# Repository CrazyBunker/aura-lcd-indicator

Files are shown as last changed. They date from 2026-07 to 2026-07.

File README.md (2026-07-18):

# ASUS AURA — LED-контроллер и LCD-дисплей

Управление ARGB LED-контроллером ASUS AURA (0b05:19af) через USB-HID.
Включает **CLI утилиту**, **MCP сервер** для OpenCode/Claude, и **ESP32-скетч** для декодирования сигнала WS2812B.

## Фотографии

### Общий вид макета
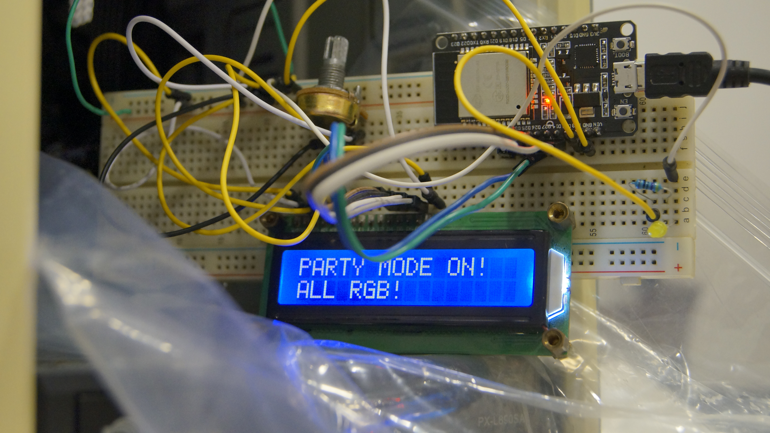
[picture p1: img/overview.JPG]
Общий вид


Плата ESP32 DevKit с подключённым HD44780 LCD (16×2) через 4-битный параллельный
интерфейс. Сигнальный провод от GPIO16 подключён к линии данных ARGB-контроллера
ASUS AURA для захвата WS2812B-кадра.

### Разъём ARGB
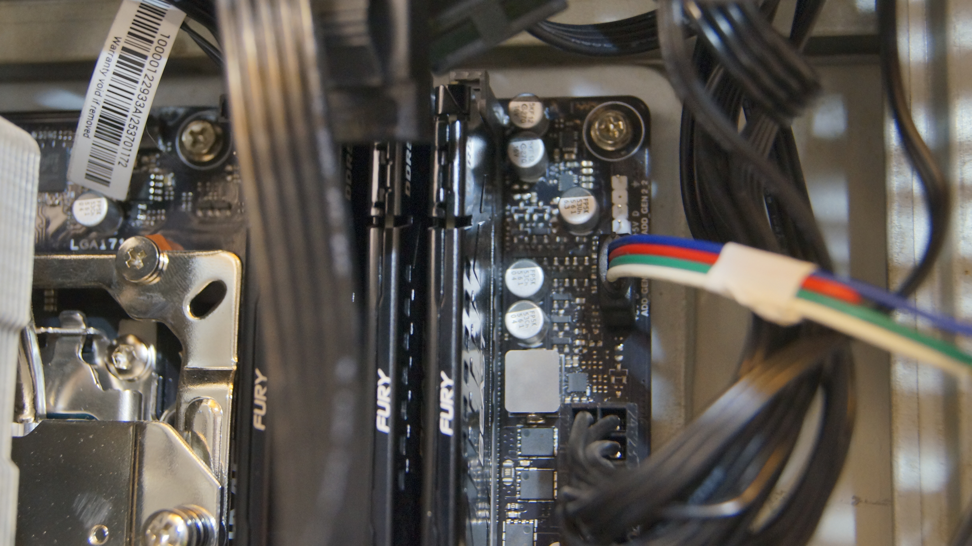
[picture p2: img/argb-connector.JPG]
Разъём ARGB


3-контактный разъём ARGB (5V, Data, GND) для подключения к материнской плате
или AURA-контроллеру. По этой линии ESP32 принимает WS2812B-сигнал через RMT.

### Схема подключения
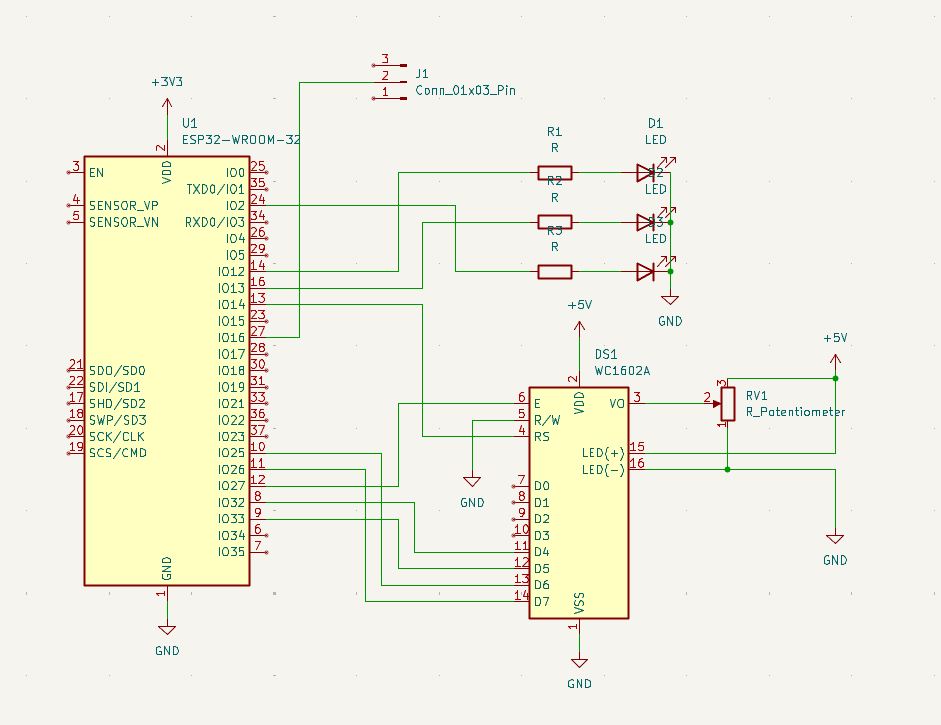
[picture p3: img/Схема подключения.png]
Схема подключения


Полная схема соединений ESP32 DevKit с HD44780 LCD, индикаторными LED и ARGB-лентой.

### Готовое устройство
Готовое устройство

ESP32 с LCD-дисплеем, подключённый к ПК. На экране отображаются данные с ARGB-контроллера.

## Быстрый старт

```bash
# Сборка (требуется Go 1.25+)
make

# Поиск устройства
./aura-indicator/bin/aura-ctl detect

# Индикатор
./aura-indicator/bin/aura-ctl set led2 static 0,0,255   # синий
./aura-indicator/bin/aura-ctl blink 255,0,0 5 200       # мигает красным
./aura-indicator/bin/aura-ctl off led2                  # выключить

# LCD дисплей (16x2, только ASCII, ≤32 символа)
./aura-indicator/bin/aura-ctl lcd "Hello, World!"

# Независимые строки (≤16 символов каждая)
./aura-indicator/bin/aura-ctl lcd-line 0 "Top line"
./aura-indicator/bin/aura-ctl lcd-line 1 "Bottom line"
```

## Примеры

Забавные скрипты для демонстрации — в каталоге `examples/`:

| Скрипт | Описание |
|---|---|
| `demo-full.sh` | Full-screen тексты: Hello World, LCD go brrrr |
| `demo-lines.sh` | Независимые строки, мигание индикатора |
| `demo-leds.sh` | 6 цветов LED + LCD не затирается |
| `demo-matrix.sh` | Отсылки к фильму «Матрица» |
| `demo-moods.sh` | Цвет индикатора под настроение |
| `demo-quotes.sh` | Знаменитые цитаты на дисплее |
| `demo-game.sh` | Игровая сцена: загрузка → бой → победа |
| `demo-rainbow.sh` | Радуга на индикаторе |
| `demo-status.sh` | Имитация прогресса (как в MCP) |

```bash
cd examples && ./demo-rainbow.sh
```

Все тексты только ASCII, ≤16 символов на строку, ≤32 full-screen.

## Сборка

```bash
make          # aura-ctl + aura-indicator → aura-indicator/bin/
make cross    # кросс-компиляция под Linux/Win/Mac (amd64 + arm64)
make clean    # удалить bin/
```

## Структура проекта

```
aura/
├── aura-indicator/         # Go-проект (CLI + MCP сервер)
│   ├── cmd/
│   │   ├── aura-ctl/       # CLI: detect, status, set, direct, lcd, blink
│   │   └── aura-indicator/ # MCP сервер (JSON-RPC stdin/stdout)
│   ├── pkg/aura/           # Go-библиотека: HID-протокол, LCD, состояние
│   ├── bin/                # Собранные бинарники
│   └── go.mod
├── aura_rmt/               # ESP32 Arduino скетч (aura_rmt.ino)
├── examples/               # Демо-скрипты
├── docs/                   # Техническая документация (PROTOCOL.md)
├── assets/                 # 3D-модели корпуса LCD (FreeCAD, STL, 3MF)
├── img/                    # Фотографии макета
├── Makefile                # Сборка проектов
└── README.md
```

## LCD (16x2 символьный дисплей через LED-ленту)

LED-лента на канале **led2** используется одновременно как индикатор (LED0)
и как 16×2 символьный дисплей (LED1..LED32, по 3 символа на LED).

**Важно:**
- Только ASCII 0x20–0x7F. Русские буквы/эмодзи → пробел.
- Индикатор (LED0) и LCD (LED1..LED32) работают **независимо**:
  `set led2 static RED` меняет только LED0, LCD-текст сохраняется.
- Строки обновляются независимо: `lcd-line 0` не затирает строку 1.

**Мэппинг:**

| Позиция 0–31 | LED (`pos/3` +1) | Канал (`pos%3`) |
|---|---|---|
| 0, 1, 2 | LED1 | R, G, B |
| 3, 4, 5 | LED2 | R, G, B |
| … | … | … |
| 30, 31 | LED11 | R, G (B свободен) |

## 3D-печатный корпус для LCD

В каталоге `assets/` находятся модели для 3D-печати корпуса LCD-дисплея:

| Файл | Описание |
|---|---|
| `LCD.FCStd` | Исходный проект в FreeCAD |
| `LCD-Body.stl` | 3D-модель для печати (STL) |
| `LCD-Body.3mf` | 3D-модель в формате 3MF |

## Команды CLI (aura-ctl)

| Команда | Аргументы | Описание |
|---|---|---|
| `detect` | — | Найти AURA-устройства |
| `status` | — | Статус: каналы, прошивка, конфиг |
| `set` | `<канал> <режим> [RGB]` | Режим: static, rainbow, breathing, off… |
| `direct` | `<канал> <RGB>...` | Прямые цвета на LED |
| `off` | `<канал>` | Выключить (для led2 — только индикатор) |
| `lcd` | `<текст>` | Full-screen, до 32 символов |
| `lcd-line` | `<строка> <текст>` | Одна строка (0 или 1), до 16 символов |
| `blink` | `<RGB> [раз] [мс]` | Мигание индикатором |

Глобальный флаг: `-d /dev/hidrawN` — путь к устройству (по умолчанию автоопределение).

### Примеры

```bash
# Эффекты
aura-ctl set led2 static 255,0,0
aura-ctl set led2 rainbow
aura-ctl set led2 breathing 0,0,255
aura-ctl off led2

# LCD
aura-ctl lcd "Hello from Go!"
aura-ctl lcd-line 0 "First line"
aura-ctl lcd-line 1 "Second line"

# Мигание
aura-ctl blink 255,0,0 5 150
```

## MCP сервер (aura-indicator)

JSON-RPC сервер по протоколу MCP (Model Context Protocol).
Используется OpenCode/Claude для управления индикатором и LCD.

Запускается агентами автоматически. Поддерживаемые инструменты:

| Инструмент | Назначение |
|---|---|
| `aura_notify_start` | Синий — задача начата |
| `aura_notify_done` | Зелёный — задача выполнена |
| `aura_notify_off` | Выключить индикатор |
| `aura_notify_question` | Красный — ожидание ответа |
| `aura_notify_importance` | Яркость синего (0–100%) |
| `aura_notify_progress` | Прогресс (0–100%) |
| `aura_lcd_print` | Текст на дисплей |
| `aura_blink` | Мигание индикатором |

## ESP32 firmware (aura_rmt/)

Скетч `aura_rmt/aura_rmt.ino`:
- **RX:** RMT-периферия на GPIO16 захватывает ARGB-сигнал
- **Декодер:** LED0 декодируется (GRB), красный → GPIO13, зелёный → GPIO12, синий → GPIO2 (PWM)
- **Serial:** `l` — live/histogram, `d` — дамп кадра, `t` — self-test

## USB-HID протокол

Контроллер — HID-устройство с 65-байтовыми пакетами (префикс `0xEC`).
Протокол совместим с OpenRGB (AuraMainboardController).

### Effect (режим)
```
0xEC 0x35 [channel_type] 0x00 0x00 [mode]
```
### Color (цвет с маской)
```
0xEC 0x36 [mask_hi] [mask_lo] 0x00 [R] [G] [B]
```
### Direct (по-LED)
```
0xEC 0x40 [channel|0x80] [start_LED] [count] [R G B...]
```
### Commit
```
0xEC 0x3F 0x55
```

## Установка (udev)

```bash
echo 'SUBSYSTEM=="hidraw", ATTRS{idVendor}=="0b05", MODE="0666"' | \
  sudo tee /etc/udev/rules.d/99-aura.rules
sudo udevadm trigger
```

## Ссылки

- `docs/PROTOCOL.md` — полная спецификация WS2812B (тайминги, структура кадра)

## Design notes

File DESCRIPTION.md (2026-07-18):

# AURA — ASUS AURA LED Controller Toolchain

**AURA** — это набор инструментов для управления LED-контроллером ASUS AURA (USB HID, VID:PID `0b05:19af`) и совместимыми клонами (AULA и др.). Позволяет управлять ARGB-подсветкой, выводить текст на 16×2 символьный LCD-дисплей через LED-ленту, а также декодировать сигнал WS2812B с помощью ESP32.

Также в проекте есть 3D-модели корпуса LCD-дисплея (`assets/`) для печати на 3D-принтере.

Проект состоит из трёх компонентов:

---

## 1. `aura-ctl` — CLI утилита (Go)

Полноценная замена Python-версии `aura_ctl.py`. Работает напрямую с HID-устройством через `/dev/hidraw*`, без внешних зависимостей.

**Возможности:**
- Обнаружение AURA-контроллера (сканирование sysfs)
- Установка режимов: static, rainbow, breathing, chase, off и ещё 14 эффектов
- Прямое управление каждым LED (direct mode)
- Вывод текста на 16×2 LCD-дисплей (full-screen и построчно)
- Мигание индикатором с настраиваемой скоростью
- Состояние LED и LCD сохраняется в JSON (`/tmp/aura_led2_state.json`)
- Индикатор (LED0) и LCD (LED1..LED32) работают независимо

**Использование:**
```bash
aura-ctl detect                      # найти устройство
aura-ctl status                      # статус и каналы
aura-ctl set led2 static 0,0,255     # синий индикатор
aura-ctl set led2 rainbow            # радуга
aura-ctl lcd "Hello, World!"         # текст на LCD
aura-ctl lcd-line 0 "First line"     # одна строка
aura-ctl blink 255,0,0 5 150         # мигание
aura-ctl off led2                    # выключить
```

---

## 2. `aura-indicator` — MCP сервер (Go)

JSON-RPC сервер по протоколу MCP (Model Context Protocol). Используется агентами OpenCode/Claude для визуальной индикации состояния на физическом устройстве.

**Инструменты:**
- `aura_notify_start` / `done` / `off` / `question` — цветовые уведомления
- `aura_notify_importance` / `progress` — яркость/прогресс (0-100%)
- `aura_lcd_print` — вывод текста на LCD (full-screen / строка)
- `aura_blink` — мигание с настраиваемыми параметрами

Работает через stdin/stdout, не требует Python.

---

## 3. `aura_rmt` — ESP32 firmware (Arduino)

Скетч для ESP32, который декодирует сигнал ARGB-ленты WS2812B с помощью RMT-периферии.

**Особенности:**
- Захват сигнала на GPIO16 (RMT)
- Декодирование LED0 из каждого кадра (GRB → 3 байта)
- Красный канал LED0 → GPIO13 (PWM, внешний красный LED)
- Зелёный канал LED0 → GPIO12 (PWM, внешний зелёный LED)
- Синий канал LED0 → GPIO2 (PWM, встроенный синий LED)
- Live-режим и histogram-режим
- Self-test: генератор тестового кадра на GPIO17 → GPIO16
- LCD-обновление не чаще 2 раз/с (anti-flicker)

---

## USB-HID протокол

Контроллер — HID-устройство (65-байтовые пакеты с префиксом `0xEC`). Протокол совместим с **OpenRGB** (AuraMainboardController).

```
Effect:  0xEC 0x35 [ch_type] 0x00 0x00 [mode]
Color:   0xEC 0x36 [mask_hi] [mask_lo] 0x00 [R] [G] [B]
Direct:  0xEC 0x40 [ch|0x80] [start] [count] [R G B...]
Commit:  0xEC 0x3F 0x55
```

---

## LCD через LED-ленту

Канал **led2** используется одновременно для индикатора (LED0) и 16×2 символьного дисплея (LED1..LED32). Каждый LED кодирует 3 символа (R, G, B каналы). Поддерживается только ASCII 0x20–0x7F.

- Индикатор и LCD работают независимо
- Строки обновляются независимо
- Состояние сохраняется и восстанавливается при перезапуске

---

## Сборка

```bash
make          # aura-ctl + aura-indicator → aura-indicator/bin/
make cross    # кросс-компиляция (Linux/Win/Mac, amd64/arm64)
make clean    # удалить bin/
```

Требуется **Go 1.25+**. Без внешних зависимостей (только стандартная библиотека).

---

## Системные требования

- **Linux** с ядром и поддержкой hidraw
- **Права доступа:** пользователь должен иметь доступ на чтение/запись к `/dev/hidraw*`
- **udev-правило:** `SUBSYSTEM=="hidraw", ATTRS{idVendor}=="0b05", MODE="0666"`
- Для ESP32: Arduino IDE или PlatformIO с поддержкой ESP32 Arduino Core

---

## Примеры

В каталоге `examples/` — 10 демо-скриптов с забавными текстами:

```bash
cd examples
bash demo-full.sh     # полный экран
bash demo-matrix.sh   # отсылки к фильму «Матрица»
bash demo-game.sh     # игровая сцена: загрузка → бой → победа
bash demo-all.sh      # все сразу
```

Каждый текст ровно 16+16=32 символа (full screen) или ≤16 символов (строка), слова не разрываются, только ASCII.

---

## Лицензия

MIT

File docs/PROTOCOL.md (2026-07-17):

# Спецификация протокола WS2812B (ASUS AURA ARGB)

## Характеристики сигнала

- **Уровни напряжения**: логическая «1» ≈ 5 В, логический «0» ≈ 0 В (тактовая частота задаётся контроллером AURA).
- **Скорость передачи данных**: 800 кГц → период бита ≈ 1,25 мкс (1250 нс).
- **Сброс (Reset gap)**: > 50 мкс (50 000 нс) непрерывного низкого уровня означает конец кадра.
- **Межкадровый период**: ≈ 16,8 мс (по данным захватов), что соответствует ~59 fps.

## Кодирование бита (WS2812B)

| Символ | Номинальный высокий (нс) | Номинальный низкий (нс) |
|---|---|---|
| `0` | ~350 нс (T0H) | ~900 нс (T0L) |
| `1` | ~900 нс (T1H) | ~600 нс (T1L) |

## Измеренные тайминги (по захватам)

| Захват | T0H нс (мин/сред/макс) | T1H нс (мин/сред/макс) | T0L нс (мин/сред/макс) | T1L нс (мин/сред/макс) | Сброс нс (сред) | Период кадра нс (сред) | fps |
|---|---|---|---|---|---|---|---|
| `digital.csv` | 309 / 317,8 / 321  | 900 / 911,8 / 920  | 889 / 900,8 / 911  | 299 / 306,7 / 311  | 16 860 562 | 16 860 562 | 59,31 |
| `digital_red.csv` | 309 / 317,6 / 330  | 900 / 910,8 / 920  | 889 / 901,5 / 911  | 299 / 307,3 / 311  | 16 828 468 | 16 828 468 | 59,42 |
| `digital_green.csv` | 309 / 317,5 / 321  | 909 / 912,9 / 921  | 889 / 901,2 / 911  | 299 / 308,1 / 311  | 16 790 629 | 16 790 629 | 59,56 |
| `digital_blue.csv`  | 309 / 317,6 / 330  | 900 / 911,5 / 921  | 889 / 901,4 / 911  | 299 / 307,3 / 311  | 16 795 901 | 16 795 901 | 59,54 |

## Структура кадра

- **Количество светодиодов**: 120 (фиксировано для ленты AURA).
- **Бит на светодиод**: 24 (8 G + 8 R + 8 B) → **байт на светодиод**: 3 (порядок GRB).
- **Всего бит в кадре**: 120 × 24 = 2 880 бит.
- **Всего байт в кадре**: 120 × 3 = 360 байт.
- **Порядок бит**: MSB-first (старший бит первым) внутри каждого байта.
- **Порядок байт**: зелёный, красный, синий (GRB) для каждого светодиода.

## Процедура декодирования (для ESP32 или аналогичного МК)

1. **Обнаружить сброс (reset gap)** — дождаться низкого уровня длительностью > 50 мкс; следующий нарастающий фронт отмечает начало нового кадра.
2. Для каждого из следующих **2 880 бит**:
   - Измерить **ширину высокого импульса** (`tH`).
   - Если `tH` < 600 нс → бит 0, иначе → бит 1 (декодер также перепроверяет последующий низкий импульс для надёжности).
   - Сдвинуть бит в текущий байт (MSB первым).
3. После 24 бит выдать тройку **GRB** одного светодиода; повторить для всех 120 светодиодов.
4. Если кадр закончился раньше (не хватает бит), дополнить нулями; если присутствуют лишние биты, обрезать до первых 360 байт.

## Таблица верификации (первый светодиод)

| Файл захвата | Байты GRB первого LED | Интерпретация RGB |
|---|---|---|
| `digital_red.csv` | `00 FF 00` | `(255, 0, 0)` |
| `digital_green.csv` | `FF 00 00` | `(0, 255, 0)` |
| `digital_blue.csv`  | `00 00 FF` | `(0, 0, 255)` |
| `digital.csv` (эталон) | `00 00 FF` | `(0, 0, 255)` |

Все остальные светодиоды (индексы 1‑119) декодируются как `00 00 00` (выключены) в каждом захвате.

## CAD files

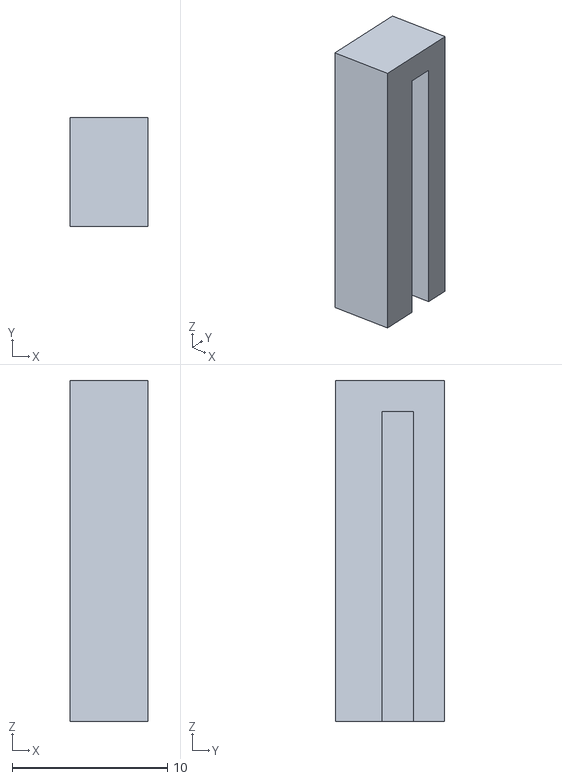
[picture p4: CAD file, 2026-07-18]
assets/LCD-Подпорка.stl
5.00 x 7.00 x 22.0

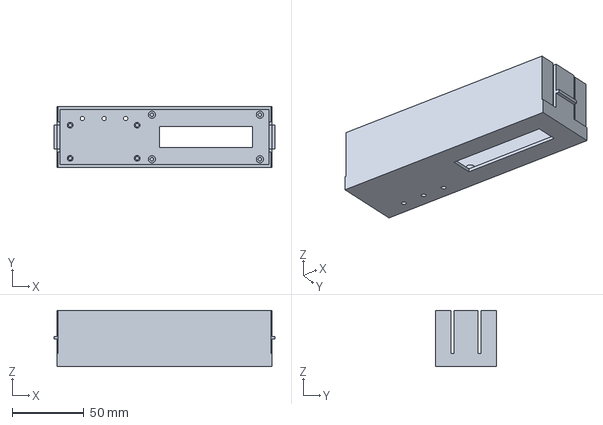
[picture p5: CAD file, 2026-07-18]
assets/LCD-Body.3mf
153.5 x 42.5 x 39.0 mm

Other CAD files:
assets/LCD.FCStd
assets/LCD-Body.stl

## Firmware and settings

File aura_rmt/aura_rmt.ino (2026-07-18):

/**
 * ASUS AURA ARGB — захват RMT RAW (RX) + генератор самопроверки (TX)
 * ========================================================================
 * Copyright (c) 2026 Vladislav Plotkin
 * SPDX-License-Identifier: MIT
 *
 * Нативный RMT HAL ESP32 Arduino Core 3.x (rmtInit/rmtWrite/rmtRead).
 *
 * RX: RMT на GPIO16 захватывает линию данных AURA как пары (HIGH длит, LOW длит)
 *     на бит WS2812B, в наносекундах. Без декодирования во время захвата.
 *
 * TX (самопроверка): RMT на GPIO17 воспроизводит известный кадр WS2812B
 *     (LED0 красный, LED1 зелёный, LED2 синий, LED3 белый, остальные чёрные). Соедините
 *     GPIO17 -> GPIO16, чтобы подать его на RX и проверить захват '0'/'1'.
 *
 * Использование:
 *   - Живой режим (по умолчанию): декодирует LED0 каждый кадр и управляет тремя PWM LED
 *     по цвету: красный канал (R) -> внешний красный LED на GPIO13, зелёный канал
 *     (G) -> внешний зелёный LED на GPIO12, синий канал (B) -> встроенный синий LED
 *     на GPIO2. Яркость каждого индикатора (PWM 0..255) следует за интенсивностью
 *     соответствующего канала, отправленной контроллером ARGB.
 *   - Отправить 'l' -> переключить живой монитор (выкл => режим гистограммы, LED выкл).
 *   - Отправить 'd' -> вывести один полный кадр RAW (H/L нс + уровни) + hex декодирование.
 *   - Отправить 't' -> переключить генератор самопроверки TX.
 *   - Отправить 'a' -> вывести информацию об авторе.
 *   - Самопроверка: ОТКЛЮЧИТЕ отвод AURA от GPIO16, соедините GPIO17->GPIO16.
 *
 * Ожидаемые декодированные байты (MSB-first, GRB):
 *   LED0 красный  : 00 FF 00
 *   LED1 зелёный  : FF 00 00
 *   LED2 синий    : 00 00 FF
 *   LED3 белый    : FF FF FF
 *   LED4          : 00 00 00
 */

#include <Arduino.h>
#include "freertos/FreeRTOS.h"
#include "freertos/task.h"
#include <string.h>

// ============================================================================
// Конфигурация
// ============================================================================

#define AURA_PIN    16
#define TX_PIN      17
#define LED_PIN     2        // встроенный LED (ESP32-DevKitC синий), активный HIGH
#define EXT_LED_PIN 15       // внешний индикаторный LED (красный), активный HIGH
#define GREEN_LED_PIN 4     // внешний индикаторный LED (зелёный), активный HIGH

// Пины 4-битного параллельного LCD (HD44780 совместимый) — все на одной физической стороне
// (левый ряд DevKit: 26, 25, 27, 33, 32) плюс D7 на GPIO14.
#define LCD_RS   14
#define LCD_EN   27
#define LCD_D4   32
#define LCD_D5   33
#define LCD_D6   25
#define LCD_D7   26
#define LCD_COLS 16
#define LCD_ROWS 2
#define LCD_SIZE (LCD_COLS * LCD_ROWS)  // 32
#define LCD_UPDATE_INTERVAL_MS 500     // обновлять LCD ~2 раз/сек (кадры приходят ~59 fps)

#define LEDC_FREQ   5000     // частота PWM для управления яркостью
#define LEDC_BITS   8        // разрешение PWM (0..255 скважность)
#define RMT_BAUD    921600
#define MAX_ITEMS   3000
#define N_LEDS_TEST 5
#define TICK_HZ     40000000UL   // 40 МГц -> 25 нс такт
#define IDLE_TICKS  4000         // 4000 * 25 нс = 100 мкс порог сброса-паузы

static const uint32_t tick_ns = 1000000000UL / TICK_HZ;   // = 25

enum { NUM_BUCKETS = 6 };

// ============================================================================
// Вспомогательные функции
// ============================================================================

static uint8_t bucket(uint32_t ns) {
    if      (ns < 300)  return 0;
    else if (ns < 600)  return 1;
    else if (ns < 1000) return 2;
    else if (ns < 1500) return 3;
    else if (ns < 3000) return 4;
    else                return 5;
}

static void print_hist(const char *label, uint32_t c[6]) {
    Serial.printf("  %s: <300=%4lu 300-600=%4lu 600-1k=%4lu 1k-1.5k=%4lu 1.5k-3k=%4lu >3k=%4lu\n",
                  label, c[0], c[1], c[2], c[3], c[4], c[5]);
}

// ============================================================================
// Кадр самопроверки TX (символы rmt_data_t)
// ============================================================================

static rmt_data_t g_tx_items[N_LEDS_TEST * 24 + 2];
static int        g_tx_n = 0;
static bool       g_tx_on = true;

// ============================================================================
// Драйвер LCD (HD44780 4-бита)
// ============================================================================

static void build_test_frame() {
    // Цвета GRB для каждого LED
    uint8_t leds[N_LEDS_TEST][3] = {
        {0, 255, 0},     // красный
        {255, 0, 0},     // зелёный
        {0, 0, 255},     // синий
        {255, 255, 255}, // белый
        {0,0,0}
    };
    int idx = 0;
    for (int i = 0; i < N_LEDS_TEST; i++) {
        uint8_t bytes[3] = { leds[i][0], leds[i][1], leds[i][2] };  // порядок G,R,B
        for (int by = 0; by < 3; by++) {
            uint8_t b = bytes[by];
            for (int k = 7; k >= 0; k--) {            // старший бит первым
                int bit = (b >> k) & 1;
                rmt_data_t it;
                if (bit) {                             // '1': ~900 нс HIGH, ~350 нс LOW
                    it.duration0 = 36; it.level0 = 1; // 900 нс
                    it.duration1 = 14; it.level1 = 0; // 350 нс
                } else {                               // '0': ~350 нс HIGH, ~900 нс LOW
                    it.duration0 = 14; it.level0 = 1; // 350 нс
                    it.duration1 = 36; it.level1 = 0; // 900 нс
                }
                g_tx_items[idx++] = it;
            }
        }
    }
    // сброс-пауза: ~300 мкс LOW (idle_threshold 100 мкс -> здесь границы кадров RX)
    rmt_data_t gap;
    gap.duration0 = 12000; gap.level0 = 0;            // 300 мкс
    gap.duration1 = 0;     gap.level1 = 0;
    g_tx_items[idx++] = gap;
    g_tx_n = idx;
}

// ============================================================================
// Состояние
// ============================================================================

static bool       g_do_raw = false;
static bool       g_live   = true;   // живой режим LED0 -> встроенный монитор LED
static uint8_t    last_g = 255, last_r = 255, last_b = 255;
static uint32_t   g_frame  = 0;
static rmt_data_t g_rx_buf[MAX_ITEMS];

// Состояние LCD
static char     lcd_buf[LCD_SIZE];
static char     lcd_buf_prev[LCD_SIZE];
static uint8_t  lcd_colors[12][3];   // LED0..LED11, каждый R,G,B
static bool     lcd_dirty = false;
static unsigned long s_last_lcd_update = 0;  // время последнего обновления LCD (ms)

// ============================================================================
// Настройка
// ============================================================================

void setup() {
    Serial.begin(RMT_BAUD);
    Serial.setTxBufferSize(8192);   // избежать повреждения кольцевого буфера при больших дампах
    delay(100);

    // Индикаторы LED с управлением PWM (яркость через LEDC)
    ledcAttach(LED_PIN, LEDC_FREQ, LEDC_BITS);
    ledcAttach(EXT_LED_PIN, LEDC_FREQ, LEDC_BITS);
    ledcAttach(GREEN_LED_PIN, LEDC_FREQ, LEDC_BITS);
    ledcWrite(LED_PIN, 0);
    ledcWrite(EXT_LED_PIN, 0);
    ledcWrite(GREEN_LED_PIN, 0);
    // плавное изменение 0->255->0 на всех индикаторах для проверки работы пинов LED
    for (int v = 0; v <= 255; v += 8) { ledcWrite(LED_PIN, v); ledcWrite(EXT_LED_PIN, v); ledcWrite(GREEN_LED_PIN, v); delay(8); }
    for (int v = 255; v >= 0; v -= 8) { ledcWrite(LED_PIN, v); ledcWrite(EXT_LED_PIN, v); ledcWrite(GREEN_LED_PIN, v); delay(8); }

    Serial.println("\n========================================================");
    Serial.println("  AURA ARGB RMT Raw Capture (RX) + TX Self-Test");
    Serial.println("========================================================");
    Serial.printf("  RX GPIO%d   TX GPIO%d   RMT tick = %u ns (%u MHz)\n",
                  AURA_PIN, TX_PIN, tick_ns, TICK_HZ / 1000000);
    Serial.println("  LCD HD44780 4-bit: RS=26 EN=25 D4=27 D5=33 D6=32 D7=14");
    Serial.println("  Self-test TX frame (GRB, MSB-first):");
    Serial.println("    LED0 red  : 00 FF 00");
    Serial.println("    LED1 green: FF 00 00");
    Serial.println("    LED2 blue : 00 00 FF");
    Serial.println("    LED3 white: FF FF FF");
    Serial.println("    LED4      : 00 00 00");
    Serial.println("  Self-test: wire GPIO17 -> GPIO16 (AURA tap off GPIO16).");
    Serial.println("  Send 'd' = raw dump+hex.  Send 't' = toggle TX.  Send 'l' = toggle live/histogram.  Send 'a' = author info.\n");

    if (!rmtInit(AURA_PIN, RMT_RX_MODE, RMT_MEM_NUM_BLOCKS_6, TICK_HZ)) {
        Serial.println("[RMT] RX init FAILED!");
    }
    rmtSetRxMaxThreshold(AURA_PIN, IDLE_TICKS);

    if (!rmtInit(TX_PIN, RMT_TX_MODE, RMT_MEM_NUM_BLOCKS_2, TICK_HZ)) {
        Serial.println("[RMT] TX init FAILED!");
    }

    build_test_frame();

    // Инициализация LCD (HD44780 4-бита)
    lcd_init();
    Serial.println("[LCD] HD44780 4-bit initialized.");
    Serial.printf("[RMT] TX frame built: %d symbols.\n", g_tx_n);

    // Запуск самопроверки TX непрерывно на Core 0, чтобы (блокирующий) rmtRead в
    // loop() на Core 1 мог всегда захватить живой кадр. rmtWrite синхронный
    // и иначе завершился бы до того, как rmtRead начнёт прослушивание.
    xTaskCreatePinnedToCore(txTask, "tx", 4096, NULL, 1, NULL, 0);

    Serial.println("[RMT] RX running, TX self-test ON. LCD ready. Waiting for data...\n");
}

// Непрерывная передача известного кадра самопроверки на GPIO17 (Core 0).
void txTask(void *param) {
    while (true) {
        if (g_tx_on) {
            rmtWrite(TX_PIN, g_tx_items, g_tx_n, 100);
            delay(8);   // пауза LOW, чтобы RX мог разделять кадры
        } else {
            delay(10);
        }
    }
}

// Декодирование ПЕРВОГО LED (24 бита = GRB) из буфера захваченных символов.
// Возвращает true если было доступно >= 24 символов (выравнивание по началу кадра).
// WS2812B передаёт GRB, старший бит первым; импульс HIGH >= 600 нс = бит 1, иначе 0.
static bool decode_first_led(const rmt_data_t *buf, int total,
                              uint8_t *g, uint8_t *r, uint8_t *b) {
    int bits = 0, byte = 0, nbytes = 0;
    uint8_t out[3] = {0, 0, 0};
    for (int i = 0; i < total && nbytes < 3; i++) {
        uint32_t d0 = buf[i].duration0 * tick_ns;
        if (d0 >= 5000) break;            // сброс-пауза -> конец кадра
        int bit = (d0 >= 600) ? 1 : 0;    // HIGH >= 600 нс => бит 1
        byte = (byte << 1) | bit;
        if (++bits == 8) { out[nbytes++] = byte; byte = 0; bits = 0; }
    }
    if (nbytes < 3) return false;
    *g = out[0]; *r = out[1]; *b = out[2];    // GRB -> (g, r, b)
    return true;
}

// Декодирование ПОЛНОГО кадра (12 LED = 36 байт = 288 бит) из захваченных символов.
// Возвращает количество декодированных байт (ожидается 36).
// Формат WS2812B GRB на LED: G, R, B (старший бит первым).
static int decode_full_frame(const rmt_data_t *buf, int total, uint8_t out[36]) {
    int bits = 0, byte = 0, nbytes = 0;
    for (int i = 0; i < total && nbytes < 36; i++) {
        uint32_t d0 = buf[i].duration0 * tick_ns;
        if (d0 >= 5000) break;            // сброс-пауза -> конец кадра
        int bit = (d0 >= 600) ? 1 : 0;    // HIGH >= 600 нс => бит 1
        byte = (byte << 1) | bit;
        if (++bits == 8) { out[nbytes++] = byte; byte = 0; bits = 0; }
    }
    return nbytes;
}

// ============================================================================
// Драйвер LCD (HD44780 4-бита)
// ============================================================================

static void lcd_pulse_en(void) {
    digitalWrite(LCD_EN, HIGH);
    delayMicroseconds(1);
    digitalWrite(LCD_EN, LOW);
    delayMicroseconds(5);
}

static void lcd_write_nibble(uint8_t nib) {
    digitalWrite(LCD_D4, (nib & 0x01) ? HIGH : LOW);
    digitalWrite(LCD_D5, (nib & 0x02) ? HIGH : LOW);
    digitalWrite(LCD_D6, (nib & 0x04) ? HIGH : LOW);
    digitalWrite(LCD_D7, (nib & 0x08) ? HIGH : LOW);
    lcd_pulse_en();
}

static void lcd_write(uint8_t val, bool is_data) {
    digitalWrite(LCD_RS, is_data ? HIGH : LOW);
    lcd_write_nibble(val >> 4);        // старшая тетрада
    lcd_write_nibble(val & 0x0F);      // младшая тетрада
    delayMicroseconds(100);
}

static void lcd_init(void) {
    pinMode(LCD_RS, OUTPUT);
    pinMode(LCD_EN, OUTPUT);
    pinMode(LCD_D4, OUTPUT);
    pinMode(LCD_D5, OUTPUT);
    pinMode(LCD_D6, OUTPUT);
    pinMode(LCD_D7, OUTPUT);

    delay(150);   // ожидание стабилизации питания

    // Классическая последовательность инициализации HD44780 4-бита
    digitalWrite(LCD_RS, LOW);
    delayMicroseconds(100);
    
    // Первая последовательность сброса
    lcd_write_nibble(0x03);
    delayMicroseconds(4500);
    
    // Вторая последовательность сброса
    lcd_write_nibble(0x03);
    delayMicroseconds(150);
    
    // Третья последовательность сброса
    lcd_write_nibble(0x03);
    delayMicroseconds(100);
    
    // Установка 4-битного режима
    lcd_write_nibble(0x02);
    delayMicroseconds(100);

    // Настройка функций: 4-бита, 2 строки, 5x8 точек
    lcd_write(0x28, false);
    // Дисплей вкл: дисплей вкл, курсор выкл, мигание выкл
    lcd_write(0x0C, false);
    // Режим ввода: инкремент, без сдвига
    lcd_write(0x06, false);
    // Очистка дисплея
    lcd_write(0x01, false);
    delay(5);
}

static void lcd_set_cursor(uint8_t row, uint8_t col) {
    uint8_t addr = (row == 0 ? 0x80 : 0xC0) | (col & 0x0F);
    lcd_write(addr, false);
}

static void lcd_write_char(char c) {
    lcd_write((uint8_t)c, true);
}

static void lcd_update_display(void) {
    if (!lcd_dirty) return;
    
    lcd_set_cursor(0, 0);
    for (int i = 0; i < LCD_COLS; i++) {
        lcd_write_char(lcd_buf[i]);
    }
    lcd_set_cursor(1, 0);
    for (int i = LCD_COLS; i < LCD_SIZE; i++) {
        lcd_write_char(lcd_buf[i]);
    }
    lcd_dirty = false;
}

static void unpack_to_lcd(const uint8_t colors[][3]) {
    bool changed = false;
    for (int i = 0; i < LCD_SIZE; i++) {
        int led_idx = i / 3 + 1;      // 1..11
        int ch = i % 3;               // 0=R, 1=G, 2=B
        uint8_t code = colors[led_idx][ch];
        char c = (code >= 0x20 && code <= 0x7F) ? (char)code : ' ';
        if (c != lcd_buf[i]) changed = true;
        lcd_buf[i] = c;
    }
    
    if (changed) {
        memcpy(lcd_buf_prev, lcd_buf, LCD_SIZE);
        lcd_dirty = true;
    }
}

// ============================================================================
// Основной цикл
// ============================================================================

void loop() {
    while (Serial.available()) {
        int c = Serial.read();
        if (c == 'd' || c == 'D') g_do_raw = true;
        if (c == 't' || c == 'T') g_tx_on = !g_tx_on;
        if (c == 'l' || c == 'L') g_live = !g_live;
        if (c == 'a' || c == 'A') print_author();
    }

    if (g_do_raw) {
        int total = 0;
        bool got_gap = false;
        // Склейка нескольких вызовов rmtRead (HW буфер = 6 блоков = 384 символа)
        // в один кадр. Останов при обнаружении символа сброс-паузы (dur0 >= 5000 нс).
        while (total < MAX_ITEMS) {
            size_t num = MAX_ITEMS - total;
            if (!rmtRead(AURA_PIN, g_rx_buf + total, &num, 200)) break;  // таймаут/нет данных
            for (size_t i = 0; i < num; i++) {
                if (g_rx_buf[total + i].duration0 * tick_ns >= 5000) { got_gap = true; break; }
            }
            total += (int)num;
            // Останов при получении полного кадра (rmtRead ограничен 384-символьным
            // HW буфером; возврат < 384 означает конец кадра, а не заполнение буфера).
            if (got_gap || num < 384) break;
        }

        // Декодирование в байты (пропуск символа сброс-паузы: dur0 >= 5000 нс).
        uint8_t out[400];
        int nbytes = 0, bits = 0, byte = 0, ones = 0, zeros = 0;
        for (int i = 0; i < total; i++) {
            uint32_t d0 = g_rx_buf[i].duration0 * tick_ns;
            if (d0 >= 5000) break;                 // сброс-пауза -> конец кадра
            int b = (d0 >= 600) ? 1 : 0;           // HIGH >= 600 нс => бит 1
            if (b) ones++; else zeros++;
            byte = (byte << 1) | b;
            if (++bits == 8) { if (nbytes < 400) out[nbytes++] = byte; byte = 0; bits = 0; }
        }

        Serial.printf("=== RAW Frame %lu: %d symbols -> %d bytes ===\n", g_frame, total, nbytes);
        for (int i = 0; i < nbytes; i++) Serial.printf("%02X", out[i]);
        Serial.println();
        Serial.printf("  bits: ones=%d zeros=%d (test frame expect 48/192)\n\n", ones, zeros);

        g_do_raw = false;
        g_frame++;
        delay(1);
        return;
    }

    // ---- Живой режим: декодирование LED0, управление встроенным LED по синему каналу ----
    size_t num = MAX_ITEMS;
    if (rmtRead(AURA_PIN, g_rx_buf, &num, 100)) {
        g_frame++;
        if (g_live) {
            uint8_t all_leds[36];   // 12 LED * 3 байта (GRB)
            int n = decode_full_frame(g_rx_buf, (int)num, all_leds);
            
            // Маршрутизация LED0 по цвету: красный канал -> внешний красный LED (GPIO13),
            // зелёный канал -> внешний зелёный LED (GPIO12),
            // синий канал -> встроенный синий LED (GPIO2). Яркость индикатора
            // следует за интенсивностью канала, полученной от контроллера ARGB.
            // формат all_leds: [G0,R0,B0, G1,R1,B1, ...]
            // LEDCWrite ожидает R на EXT_LED_PIN, G на GREEN_LED_PIN, B на LED_PIN
            ledcWrite(EXT_LED_PIN,  all_leds[1]);   // R0
            ledcWrite(GREEN_LED_PIN, all_leds[0]);  // G0
            ledcWrite(LED_PIN,     all_leds[2]);    // B0
            
            // Заполнение lcd_colors для LED0..LED11 (порядок RGB для unpack_to_lcd)
            for (int i = 0; i < 12; i++) {
                int base = i * 3;   // формат GRB
                // Сохранение RGB для удобства: R=base+1, G=base+0, B=base+2
                lcd_colors[i][0] = all_leds[base + 1];   // R
                lcd_colors[i][1] = all_leds[base + 0];   // G
                lcd_colors[i][2] = all_leds[base + 2];   // B
            }
            
            // Декодирование и отображение на LCD — только 1 раз в секунду
            // (кадры приходят ~59 fps, LCD физически не успевает обновляться так часто)
            unsigned long now = millis();
            if (now - s_last_lcd_update >= LCD_UPDATE_INTERVAL_MS) {
                unpack_to_lcd(lcd_colors);
                lcd_update_display();
                s_last_lcd_update = now;
            }
            
            if (all_leds[0] != last_g || all_leds[1] != last_r || all_leds[2] != last_b) {
                Serial.printf("LED0 G=%3d R=%3d B=%3d -> GPIO%d(red)=%3d  GPIO%d(green)=%3d  GPIO%d(blue)=%3d\n",
                               all_leds[0], all_leds[1], all_leds[2],
                               EXT_LED_PIN, all_leds[1], GREEN_LED_PIN, all_leds[0], LED_PIN, all_leds[2]);
                last_g = all_leds[0]; last_r = all_leds[1]; last_b = all_leds[2];
            }
            
        } else {
            ledcWrite(LED_PIN, 0);
            ledcWrite(EXT_LED_PIN, 0);
            ledcWrite(GREEN_LED_PIN, 0);
            uint32_t h0[NUM_BUCKETS] = {0}, h1[NUM_BUCKETS] = {0};
            for (size_t i = 0; i < num; i++) {
                h0[bucket(g_rx_buf[i].duration0 * tick_ns)]++;
                h1[bucket(g_rx_buf[i].duration1 * tick_ns)]++;
            }
            Serial.printf("F%lu n=%d | ", g_frame, (int)num);
            print_hist("HIGH", h0);
            print_hist("LOW ", h1);
            Serial.println();
        }
    } else {
        delay(10);   // нет данных в течение 100 мс
    }
    delay(1);
}

// ============================================================================
// Author info
// ============================================================================

static void print_author(void) {
    Serial.println("\n----------------------------------------");
    Serial.println("  AURA ARGB RMT Capture");
    Serial.println("  Copyright (c) 2026 Vladislav Plotkin");
    Serial.println("  SPDX-License-Identifier: MIT");
    Serial.println("----------------------------------------\n");
}

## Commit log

2026-07-17 Initial release: Go rewrite, CLI, MCP server, ESP32 firmware, LCD support
    - Full Go rewrite of Python aura_ctl.py
    - CLI (aura-ctl) with detect, status, set, direct, off, lcd, blink, author
    - MCP server (aura-indicator) with JSON-RPC over stdin/stdout
    - Protocol: direct USB HID packets, state merge, LCD text encoding
    - ESP32 firmware: RMT capture, self-test TX, HD44780 LCD support
    - 10 demo scripts in examples/
    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
2026-07-17 Add LCD verification tests + gitignore img/
    - protocol_test.go: BuildDirectPackets count field, BuildLEDColors
    position mapping, end-to-end full roundtrip test
    - .gitignore: exclude img/ directory (photos/screenshots)
    The Go→AURA→ESP32 data flow is verified correct by tests.
    The last 3 chars of line 2 (positions 29-31) map correctly through:
    state.LCD[9][2] (pos29), state.LCD[10][0] (pos30), state.LCD[10][1] (pos31)
    → full[10..11] → BuildDirectPackets → strip LEDs 10,11 → ESP32 decode
    No software bug found in the Go pipeline or ESP32 decode path.
2026-07-17 firmware: fix LCD truncation at positions 29-31
    Root cause: ESP32 RMT RX channel had only 4 memory blocks (256
    items), insufficient for 12 LCD LEDs (289 items needed). Data
    wrapped in the ring buffer, losing LED-10 B (position 29) and
    LED-11.
    Fix:
    - RX: 4→6 blocks (384 items = 16 LEDs margin)
    - TX: 4→2 blocks (128 items, enough for reduced test frame)
    - N_LEDS_TEST: 10→5 (TX frame 241→121 items, fits in 2 blocks)
    - Adjusted raw dump loop threshold: 256→384 symbols
    Total RMT blocks now: 6(RX) + 2(TX) = 8 (max available).
    [aura_rmt.ino]
2026-07-17 state file next to binary + remove status command
    - state file: aura_led2_state.json хранится рядом с бинарником
    (os.Executable + filepath.Dir), а не в /tmp/
    - os.WriteFile вместо os.Rename — свой каталог, sticky-bit не мешает
    - LoadState/SaveState восстановлены, работает как раньше
    - удалена команда status из aura-ctl
2026-07-17 photos: add overview and argb-connector photos + README
    - renamed _DSC7803.JPG → overview.JPG (full setup)
    - renamed _DSC7809.JPG → argb-connector.JPG (ARGB connector)
    - added photo section to README with descriptions
    - removed stale 'status' command references from README
    - added img/ to project structure tree
2026-07-17 examples: add demo-random.sh — запускает случайный demo-скрипт
2026-07-17 ci: add GitHub Actions release workflow
    Собирает aura-ctl + aura-indicator под Linux/Windows/macOS
    (amd64 + arm64) при пуше тега v*, загружает в Release с
    sha256 checksums.
2026-07-17 ci: remove stale build.yml (from arduino-mcp)
2026-07-17 make: add release target
    make release VERSION=v1.0.0 собирает cross, пакует
    в release/, создаёт checksums, тегирует и пушит.
    GitHub Actions создаёт Release по тегу v*.
2026-07-17 firmware: add green indicator LED on GPIO12
    - GREEN_LED_PIN 12 с PWM (LEDC)
    - G0 (green channel) из LED0 -> GPIO12
    - startup fade test включает все 3 LED
    - выключается в histogram mode
    - обновлён serial-лог
2026-07-18 docs: add connection diagram, status command, green LED documentation
    - Добавлена схема подключения (img/Схема подключения.png) и ссылка в README.md
    - Добавлена команда status в aura-ctl (информация об устройстве, каналах)
    - Исправлен URL репозитория в aura-ctl
    - Удалён устаревший build.yml
    - Обновлена документация: GPIO12 (зелёный LED) в DESCRIPTION.md, README.md и заголовке скетча
    [aura_rmt.ino]
2026-07-18 feat: add 3D-printed LCD case models (FreeCAD/STL/3MF)
    - Добавлены 3D-модели корпуса LCD (assets/):
    - LCD.FCStd — проект FreeCAD
    - LCD-Body.stl — для 3D-печати
    - LCD-Body.3mf — формат 3MF
    - Обновлена структура проекта в README.md и DESCRIPTION.md
    [LCD-Body.3mf, LCD-Body.stl, LCD.FCStd]
2026-07-18 feat: add finished device photo and update pin mapping
    - Add 'Finished Device' section to README with PC.jpg photo
    - Update LCD pin mapping (EXT_LED_PIN 13->15, GREEN_LED_PIN 12->4)
    - Add 3D-printed LCD support bracket model (LCD-Подпорка.stl)
    - Update LCD case FreeCAD model
    [LCD-Подпорка.stl, LCD.FCStd]
